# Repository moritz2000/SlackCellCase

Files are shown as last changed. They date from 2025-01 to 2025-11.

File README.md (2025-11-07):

# SlackCellCase
This repository contains the source files to generate a 3D printable case for the [SlackCell](https://github.com/philipqueen/SlackCellESP32)

# Preperation
Download this repository with the following command: 

```bash
git clone --recurse-submodules
```

Install [Openscad](https://openscad.org/downloads.html#snapshots), you want one of the developer snapshots, because they compile waaaaay faster.

To view the models, just open the file `case.scad` with openscad.

To export the models into different stl files execute the following commamd from the terminal TWO TIMES:

```bash
python libs/partsScad/multipart.py case.scad
```

# Printing
The different parts need to be printed in different materials:
hard material (e.g. PETG):
- `case.stl`
- `lid.stl`

flexible material(e.g. TPU):
- `cell_holder.stl`
- `usb_plug.stl`
- `sd_plug.stl`
- `gasket.stl`

Instead of the gasket.stl you might also print the `lid_silicon_mold.stl` in a hard material and use that to directly inject silicon on the perimeter of the lid. That probably makes a better seal than a printed gasket.

If you use PrusaSlicer you can use the preconfigured 3mf file.

If you updated your stl files, you can reload them with F5. If you see a file selector on reload without any indication of which file to select, then cancel. Instead reload the files induvidually. (Right click models in the right panel)

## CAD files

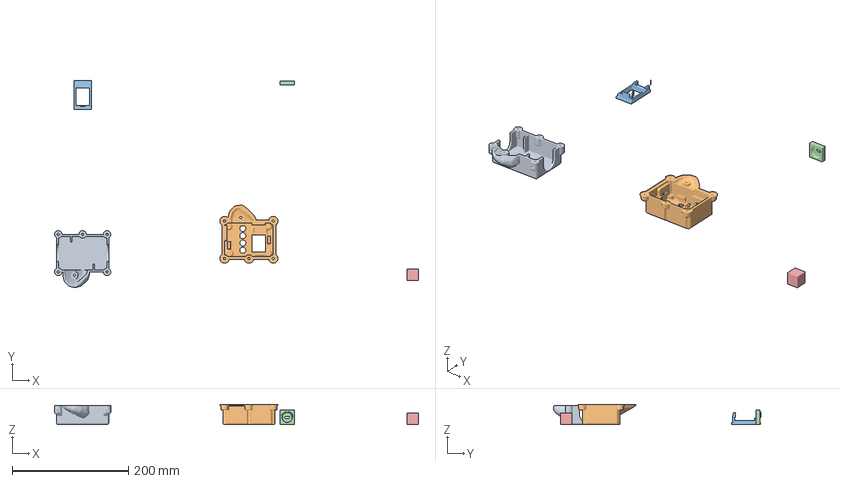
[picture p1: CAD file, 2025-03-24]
case.3mf
625.2 x 356.3 x 34.8 mm
case.stl
lid.stl
pcb_screws.stl
usb_plug_hole.stl
Shape-Box

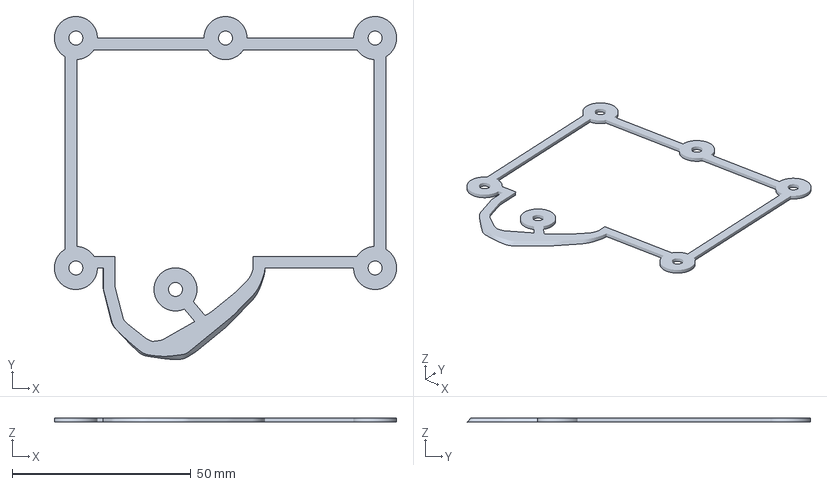
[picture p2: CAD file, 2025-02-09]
gasket.3mf
95.8 x 96.0 x 1.25 mm

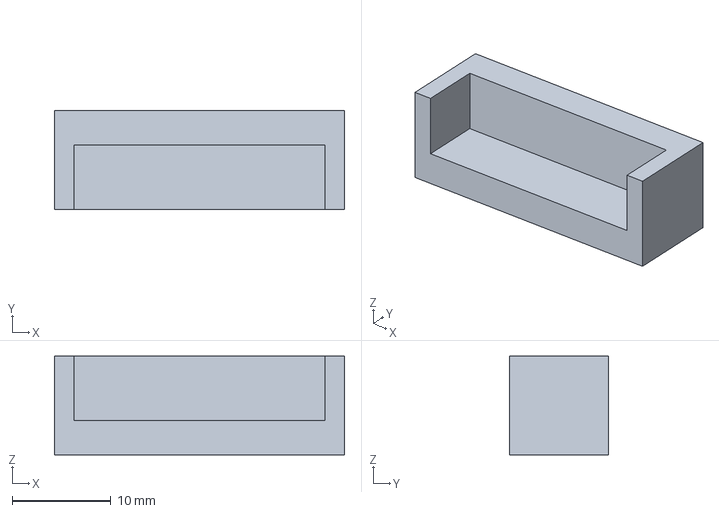
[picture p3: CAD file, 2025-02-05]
cell_holder.3mf
29.4 x 10.0 x 10.0 mm

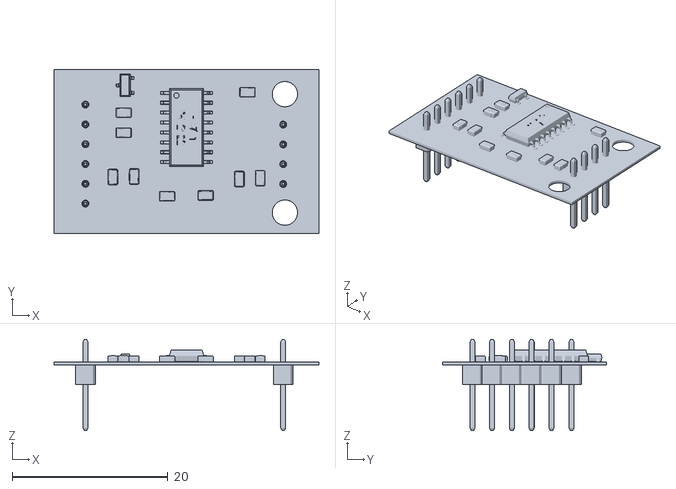
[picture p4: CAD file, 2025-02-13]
GrabCad/HX711/HX711_simple.stl
34.0 x 21.0 x 11.7

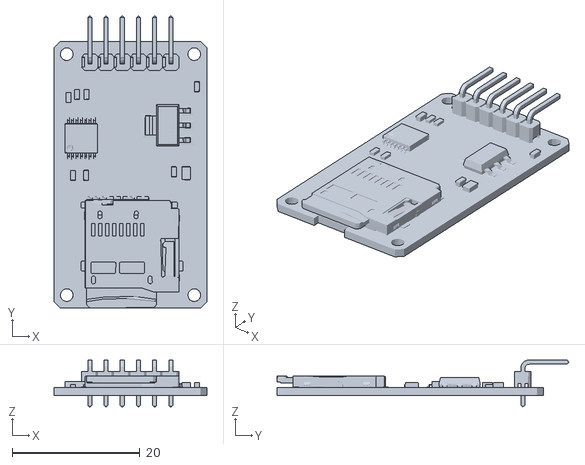
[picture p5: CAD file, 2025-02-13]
GrabCad/tf-micro-sd-card-memory-modul-arduino-1.snapshot.3/Product_TF Micro SD Card Memory Modul Arduino_simple.stl
24.0 x 45.8 x 7.35

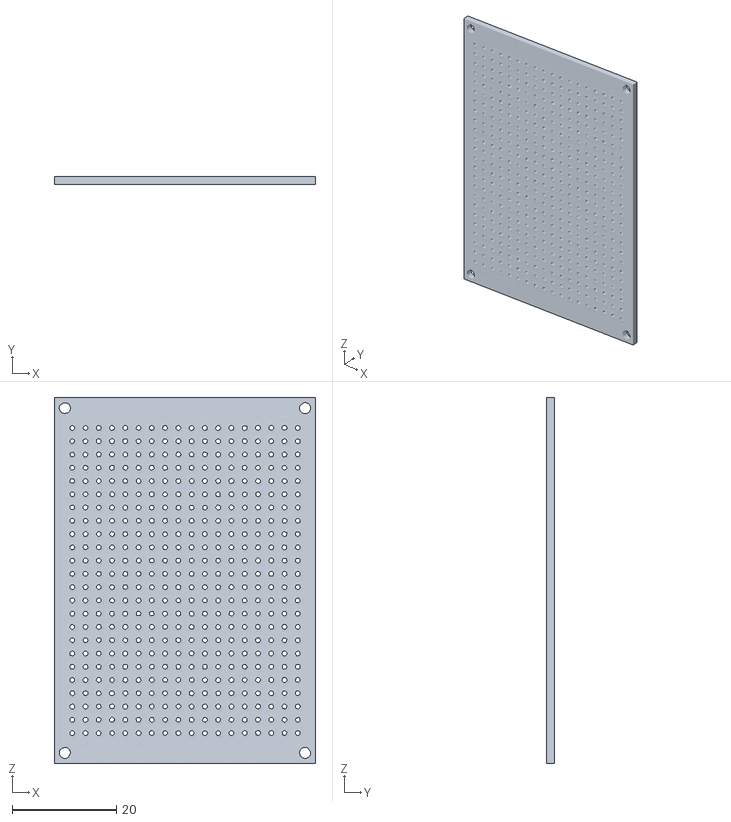
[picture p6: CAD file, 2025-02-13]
GrabCad/universal_board_50x70mm-1.snapshot.2/Universal_board_50x70mmFreeCad_simple.stl
50.0 x 1.60 x 70.1

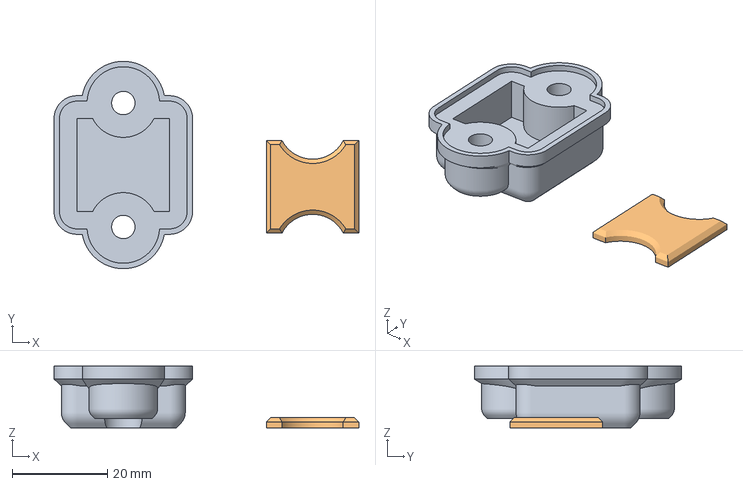
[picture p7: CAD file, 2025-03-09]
tests/water_and_screw_PETG.3mf
64.0 x 43.5 x 13.0 mm
water_and_screw_PETG.stl
water_and_screw_mold_PETG.stl

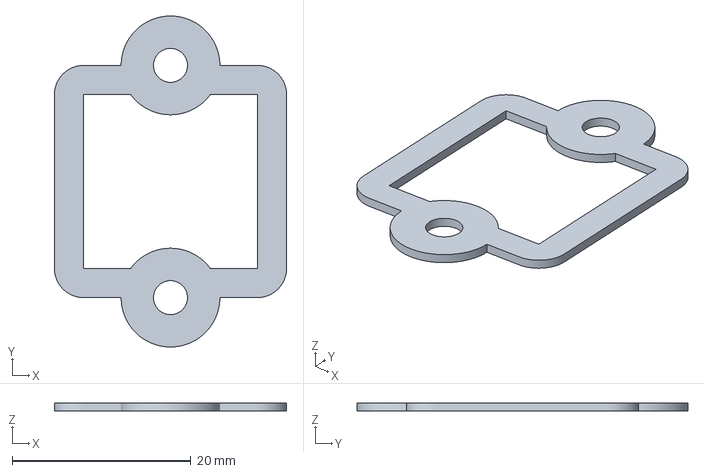
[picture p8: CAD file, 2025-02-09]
tests/water_and_screw_TPU.3mf
26.0 x 37.1 x 0.95 mm

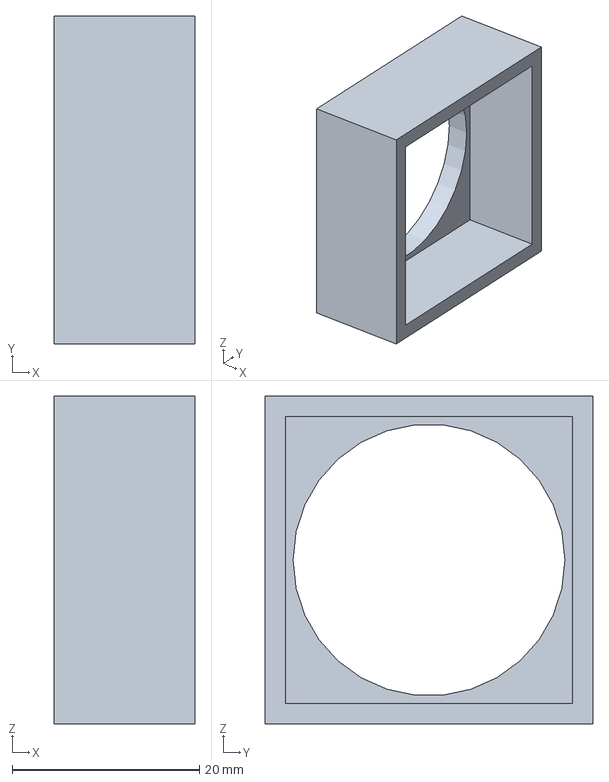
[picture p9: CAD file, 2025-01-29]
tests/tiny_nut_gasket_cube.3mf
15.0 x 35.0 x 35.0 mm

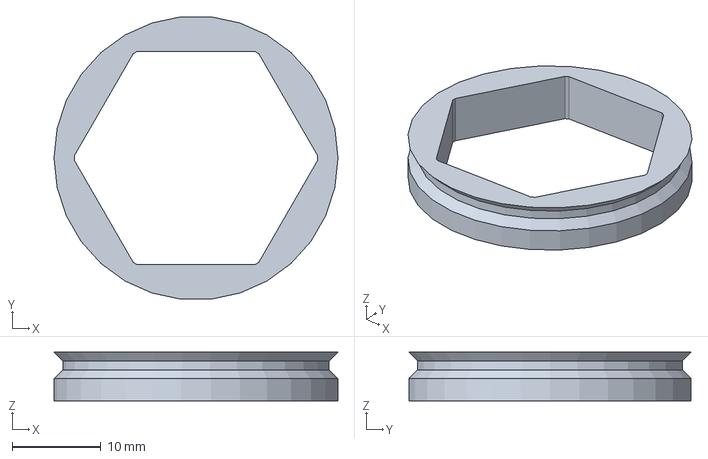
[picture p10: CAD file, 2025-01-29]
nut_gasket.3mf
32.0 x 31.8 x 5.50 mm

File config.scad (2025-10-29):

include <libs/BOSL2/std.scad>

//these includes are made to base some dimensions on the variables in them
include <loadCell.scad>
include <pcb.scad>
include <battery.scad>
include <usb_hole_plug.scad>
include <slicer_config.scad>

//ignore message about changes in BOSL api
$align_msg = false;

//This file contains most of the global variables, so that the different scad files can all access them

///////////////////////////////////
//Settings for Preview and Rendering
//Only generate the round features with high detail when it is rendering for exporting the stl. This gives us faster previews
$fa = $preview ? 10 : 1;
$fs = $preview ? 1 : min(layer_height, 0.25);

//used to get section views. Use only false or $preview. This way the render is unaffected.
show_only_left_half = false;//$preview;
show_only_front_half = false;//$preview;
show_only_right_half = false;//$preview;

//separate parts by this amount in x for rendering, for easy inspection
render_spacing = 100;

/////////////////////////////////////
//These settings define the dimensions of the case. Some dimensions however are derived from the refernece parts (pcb, loadcell and battery).

//gap to leave between the inner walls of the case and the outer dimensions of the load cell
cell_to_case_gap_xy = 3.5;
cell_to_case_gap_z = 2;

//minimum wall thickness in xy and z
case_wall = s6_walls;
case_rounding = case_wall;
case_screw_rounding = 2;


gasket_thickness = 1.25;
pcb_to_battery_spacing = 4;

//Variables for corner piece out of TPU which fixes the loadcell inside of the case, while still allowing it to flex
cell_holder_width = 10;
cell_holder_rounding = case_rounding - case_wall;
//prevents squezing the loadcell too much, which would already exert a force.
case_cell_holder_stoppers_gap = 0.3;



//Config for the window that get's inserted to protect the screen. I cut mine out of an empty 3d printing filament spool which is PC material, and is rounded.
//For a flat one, the variables and module "pcb_display_window" have to be slightly changed

//sets how many mm the window will side below the outside surface of the lid
window_inset = 0.9;
window_dim = [33, 24.25, 6]; //with a curved window, this is measured when the window is sitting on a flat surface, from the surface to the top most point
window_radius = 58;
//Vector for defining for x and y material to leave besides the window, the higher the number the less you'll see on the display later (worse viewing angle)
//z is just there for making the cutout
window_border = [1.5, 0.5, -case_wall];
window_holder_wall = s4_walls;
//leave some space for glueing it in
window_slop = 0.4;

//prevents pressure on the case to damage the display
display_to_window_dist = 0.2; //so small, because window is curved

//diameter of the holes of the four buttons under the display
button_hole_dia = 10.4;

sd_plug_grip_dia = 24;

bottom_pcb_to_lid_opening_z_dist = 12;

////////////////////////
//Calculated dimensions:

case_inner_dim_xy = [loadcell_dim.x, loadcell_dim.y] + repeat(2*cell_to_case_gap_xy, 2);
case_inner_dim_z = loadcell_dim.z + 2*cell_to_case_gap_z;

case_outer_dim_xy = case_inner_dim_xy + repeat(2*case_wall, 2);

//Stuff for the sd and usb c plugs
outer_lid_to_usb = case_outer_dim_xy.y/2 + pcb_usb_position.x;
usb_plug_inner_height = outer_lid_to_usb - s2_walls;

outer_lid_to_sd = case_outer_dim_xy.x/2 - pcb_sd_position.y;
sd_plug_inner_height = outer_lid_to_sd - s2_walls;

usb_plug_thread_config = thread_config(17, usb_plug_inner_height);
sd_plug_thread_config = thread_config(20, sd_plug_inner_height);

//distance between inner top surface of the lid and the topmost surface from the display in z direction
lid_to_display_dist = window_dim.z - case_wall + window_inset + display_to_window_dist;

lid_internal_height = lid_to_display_dist + pcb_dim.z + bottom_pcb_to_lid_opening_z_dist;

//transform of the pcb relativ to BOTTOM of lid
//Usage: multmatrix(pcb_transfrom_matrix)
//         pcb(); //or anything else you want to have in this transformation
pcb_transform_matrix = up(lid_internal_height + gasket_thickness - lid_to_display_dist) * zrot(90);

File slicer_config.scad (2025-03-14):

//////////////////////////////////////
//Slicer specific settings for the PETG parts (case and lid)
layer_height = 0.2;
//Recommended wall thickness from slicer
//With Prusa Slicer, read them of in Print Settings -> Layer and Perimeters -> Vertical Shells
s2_walls = 1.14;
s4_walls = 2.21;
s6_walls = 3.28;

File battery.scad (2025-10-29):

include <libs/BOSL2/std.scad>

//battery() show_anchors();
battery_dim = [52.5, 41, 5];


module battery(anchor = CENTER, spin = 0, orient = UP){
    recolor("purple") cuboid(battery_dim, anchor = anchor, spin = spin, orient = orient, rounding = 2.5, edges = "X");
}

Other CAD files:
button_insert.scad
case.scad
loadCell.scad
nut_gasket.scad
pcb.scad
usb_hole_plug.scad

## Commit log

2025-01-29 rough appearance of the case, not ready for printing
    [battery.scad, case.scad, gasket.3mf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]
2025-02-05 Case parts are now generated together and then split into case, gasket, and lid - improved cable channel - added cross section views - increase detail on render
    [battery.scad, case.scad, cell_holder.3mf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]
2025-02-09 Made lower case half ready for first print - more documentation - screw point is made more modular - added flexible chamfering and rounding options to screw_point -removed old unused modules
    [case.3mf, case.scad, gasket.3mf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]
2025-02-13 added screen and button cutouts and screw studs for attaching the pcb - prototype for closing the lid (lid_seal) - more comments - use simplified stl files for the pcb reference
    [HX711_simple.stl, Product_TF Micro SD Card Memory Modul Arduino_simple.stl, Universal_board_50x70mmFreeCad_simple.stl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]
2025-02-14 Pulled out the variables into config.scad - small naming improvements - also documented them better
    [case.scad, config.scad, loadCell.scad]
2025-03-09 Added twist joint library from previous model, which is one idea for a closable hole in front of the usb connector and sd slot - reduced rounding of screw point cylinders, for better support while pr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
    [case.3mf, case.scad, config.scad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]
2025-03-10 Render and preview optimizations, significantly reduces number of CSG tree elements. This makes moving around in the preview so much more comfortable. This includes no geometry changes except the dea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
    [case.scad]
2025-03-10 reduced space between top surface of lid and display
    [config.scad]
2025-03-10 made one part of the case_buldge straight, which creates a better mating between lid and case
    [case.scad]
2025-03-13 Pcb is now fixed with threaded inserts and the pcb board pushers. This simplifies assembly in comparison to the inserted nuts from before - moved pcb pushers and pcb screws to the pcb file - added se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
    [case.scad, config.scad, pcb.scad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]
2025-03-14 Added screwable usb plug - more views - changed the colors of case and lid
    [case.scad, pcb.scad, usb_hole_plug.scad]
2025-03-14 Added nice fillets to the counterbore for the screws on the case corners
    [case.scad]
2025-03-14 Added a lip to the lid which will contain the silicon injected on the edge
    [case.3mf, case.scad, config.scad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]
2025-03-23 Improved chamfered 3d lip for the lid
    [case.3mf, case.scad]
2025-03-24 Added threaded sd plug and corresponding hole - made the threaded plug more modular, to be able to use it for SD and for USB - fixed splitting of the case_buldge for case
    [case.3mf, case.scad, config.scad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]
2025-08-18 Added a model for a TPU insert for the buttons
    [button_insert.scad, case.scad]
2025-08-18 Added a mold model to be able to do a silicon gasket - moved generation of lid_2d_interface to the top
    [case.scad]
2025-08-18 small dimension changes to the hole plugs
    [usb_hole_plug.scad]
2025-08-18 Restructured export documentation
    [case.scad]
2025-10-29 added libraries BOSL2 and partsScad
    [battery.scad, button_insert.scad, case.scad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]
